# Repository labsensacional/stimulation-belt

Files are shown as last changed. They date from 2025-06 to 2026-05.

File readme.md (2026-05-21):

# Collar de Estimulación

En este proyecto mostramos como clonar el control de un collar de adiestramiento que tiene opciones de estimulos por vibracion, sonido e impulsos electricos.

## Captura de la señal

Para esto usamos el [Trainer 3](https://mundomascotas.com.ar/tienda/collar-de-adiestramiento-para-perros/trainer-3/) y el [flipper zero](https://en.wikipedia.org/wiki/Flipper_Zero) que amablemente nos prestaron Matt y Gia respectivamente.

[KinkyToyMaker](https://www.instagram.com/kinkytoymaker/?hl=en) grabó las señales que estan en la carpeta `subs`.

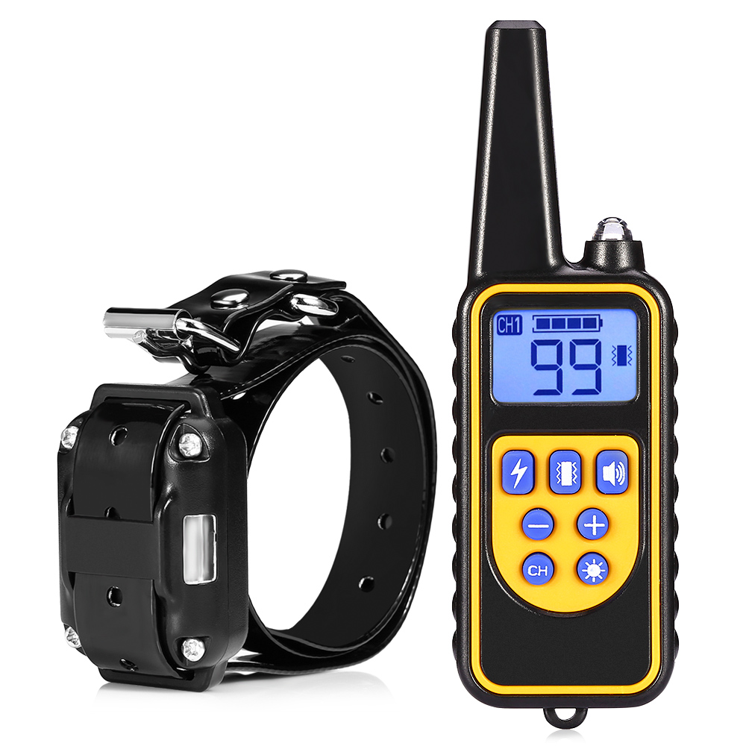
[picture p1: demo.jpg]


Compramos el collar sin control [acá](https://mundomascotas.com.ar/tienda/collares-extras/collar-extra-trainer3/)

## Hardware

Compramos distintos modulos RF de 433 MHZ para OOK y lo conectamos a una ESP32. Para debuggear y lograr que termine de funcionar todo nos guiamos de [este tutorial](https://youtu.be/LbCDpbWrdlQ?si=hX0qrkrM-xSeYEQN), el cual plantea conectar a la placa de sonido el receptor para grabar las señales que se reciben y comparar las del control que se quiere clonar con la de nuestro emisor.

- https://www.mercadolibre.com.ar/modulo-rf-transmisor-y-receptor-433-mhz-arduino/p/MLA32487770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
    - De este anduvo el receptor y no el transmisor

- https://articulo.mercadolibre.com.ar/MLA-780605460-emisor-receptor-superheterodino-433-armodltxrxwl102-_JM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
    - De este anduvo el transmisor y no el receptor

## Sketches ESP32

| Carpeta | Descripción |
|---|---|
| `src/Telegram_Bot` | Control por comandos de Telegram sobre WiFi |
| `src/BLE_Keyboard` | Dispara shocks al presionar teclas en un teclado BLE HID |
| `src/Dual_Mode` | **Fusión de ambos** — switchea entre modos con el botón BOOT |
| `src/Numpad_Serial` | **Sin BLE ni WiFi** — numpad 4×4 cableado directo + control por puerto serial |

### Numpad_Serial

Control standalone sin radio: un teclado matricial 4×4 conectado directamente a 8 pines del ESP32, más comandos por puerto serial desde una PC.

| Tecla | Función |
|---|---|
| `7` | Shock collar 1 |
| `8` | Shock collar 2 |
| `9` | Shock ambos |
| `4` / `5` | Nivel collar 1/2 +1 |
| `1` / `2` | Nivel collar 1/2 -1 |
| `0` | Ambos niveles +1 |
| `*` | Ambos niveles -1 |
| `6` / `3` | Test collar 1/2 (vibra + beep) |
| `#` | Reset niveles a 1 |

Incluye dos interfaces para la PC:
- `shocker_serial.py` — script Python (requiere `pip install pyserial`)
- `shocker_serial.html` — página web, abrila en Chrome o Edge (usa Web Serial API, no necesita instalar nada)

> **Windows:** puede ser necesario instalar el driver USB-serial del chip de la placa.
> El driver para CH340/CH341 (el más común en placas NodeMCU) o CP210x se puede bajar de:
> https://www.silabs.com/documents/public/software/CP210x_Universal_Windows_Driver.zip

### Dual_Mode — cómo switchear de modo

| Acción al encender | Resultado |
|---|---|
| No tocar nada | Arranca en el modo guardado (Telegram por defecto) |
| Mantener BOOT < 2 s y soltar | Cambia de modo (Telegram ↔ BLE Keyboard), guarda y reinicia |
| Mantener BOOT ≥ 2 s | Borra credenciales WiFi guardadas y reinicia |

El LED parpadea rápido mientras se sostiene el botón para confirmar que fue registrado.

### Compilar y subir

`Dual_Mode` requiere el esquema `huge_app` (WiFi + BLE juntos no entran en la partición por defecto):

```bash
~/.local/bin/arduino-cli compile \
  --fqbn "esp32:esp32:esp32:PartitionScheme=huge_app" \
  --upload --port /dev/ttyUSB0 \
  "src/Dual_Mode"
```

Para los sketches individuales:

```bash
~/.local/bin/arduino-cli compile \
  --fqbn esp32:esp32:esp32 \
  --upload --port /dev/ttyUSB0 \
  "src/Telegram_Bot"   # o src/BLE_Keyboard
```

## Proyectos Relacionados

- https://pishock.com/
- https://openshock.org/
    - https://wiki.openshock.org/hardware/shockers/caixianlin
- https://github.com/Nat-the-Kat/caixianlin_remote_shocker

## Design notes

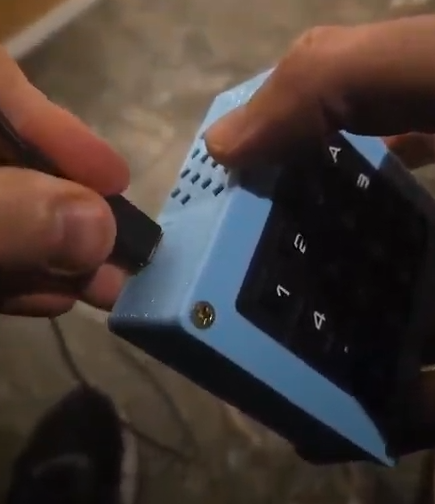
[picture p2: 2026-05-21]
src/Numpad_Serial/hardware/case-usbc.png

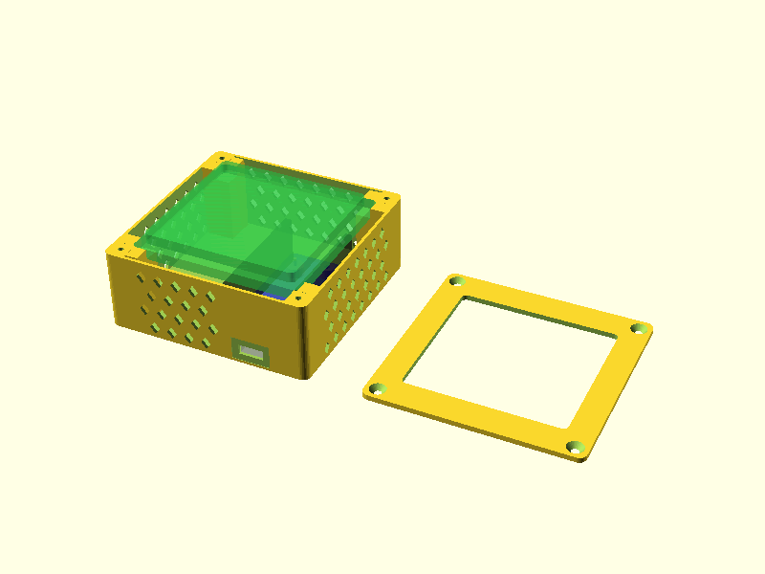
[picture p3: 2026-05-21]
src/Numpad_Serial/hardware/keypad_box_017.png

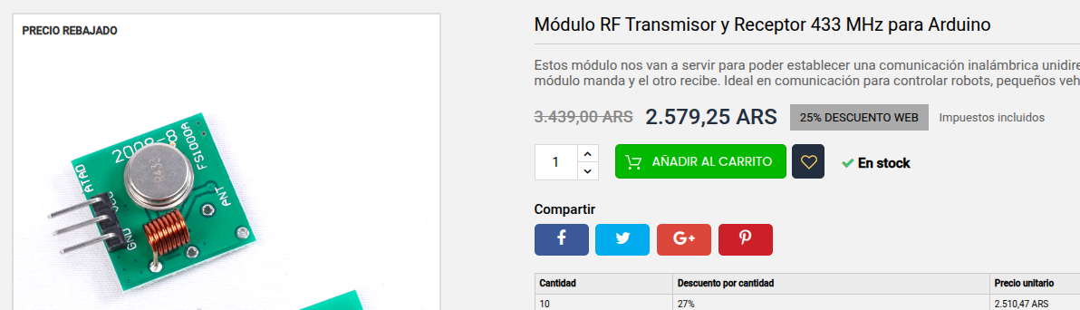
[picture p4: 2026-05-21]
src/Numpad_Serial/hardware/emisor433MHz.png

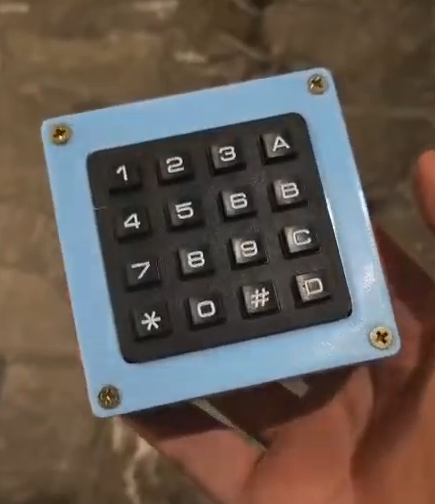
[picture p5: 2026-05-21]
src/Numpad_Serial/hardware/case.png

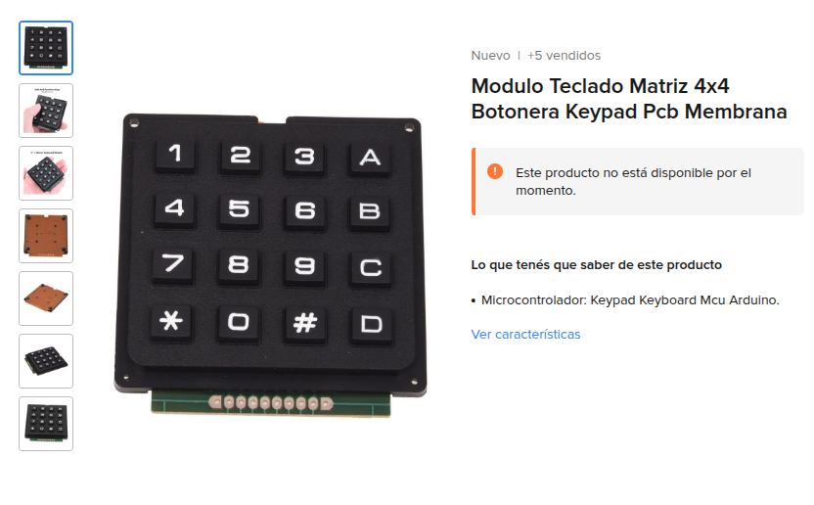
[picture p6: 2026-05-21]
src/Numpad_Serial/hardware/botonera.png

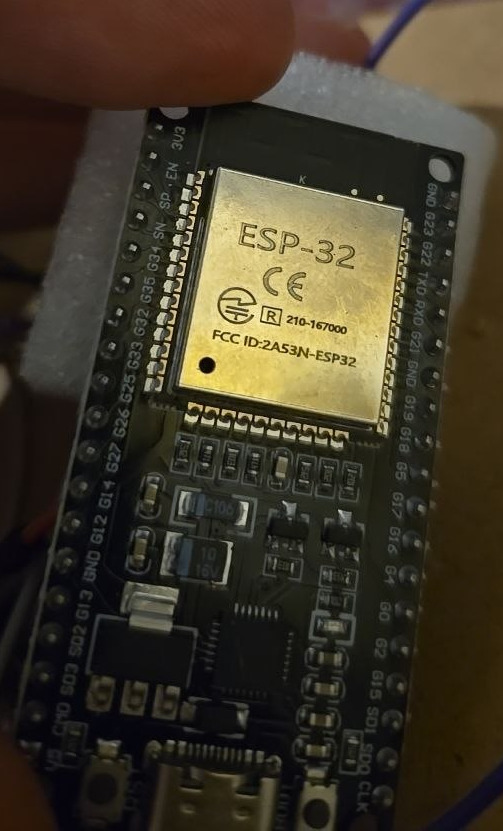
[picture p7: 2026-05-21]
src/Numpad_Serial/hardware/esp32-usbc.jpg

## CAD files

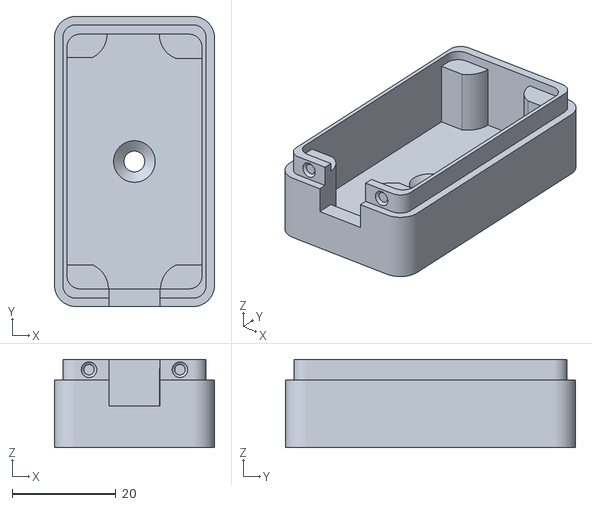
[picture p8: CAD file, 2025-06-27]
ESP Version/NodeMCU_bottom.stl
30.8 x 55.8 x 17.0

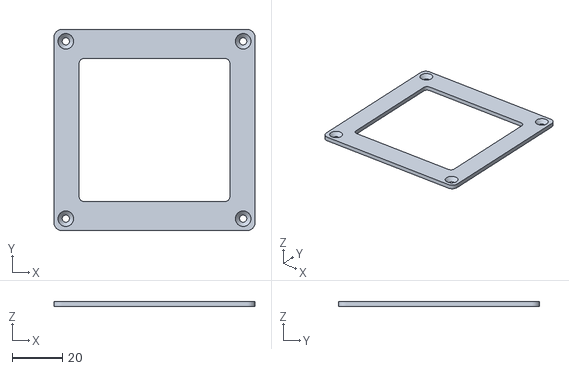
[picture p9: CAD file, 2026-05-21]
src/Numpad_Serial/hardware/keypad_box_017_lid.stl
80.0 x 80.0 x 2.00

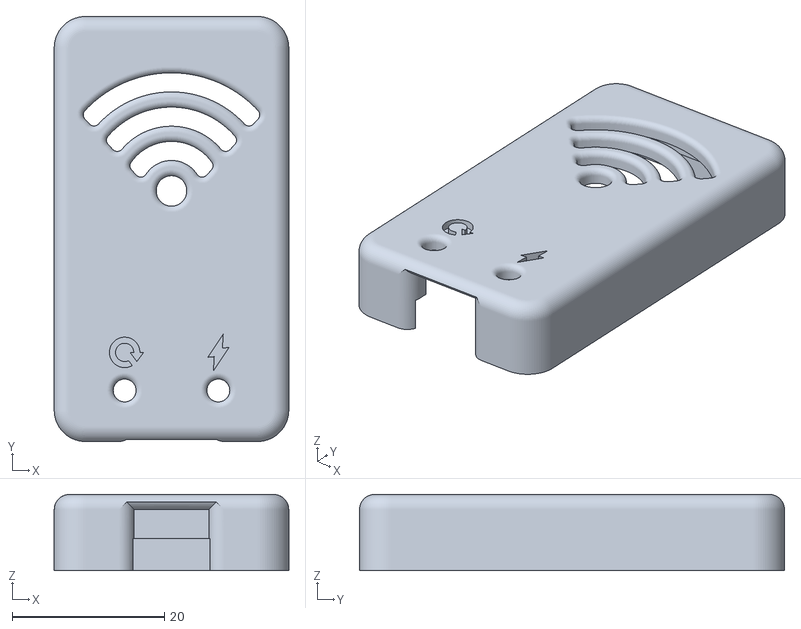
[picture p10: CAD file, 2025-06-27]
ESP Version/NodeMCU_top.stl
30.8 x 55.8 x 10.00

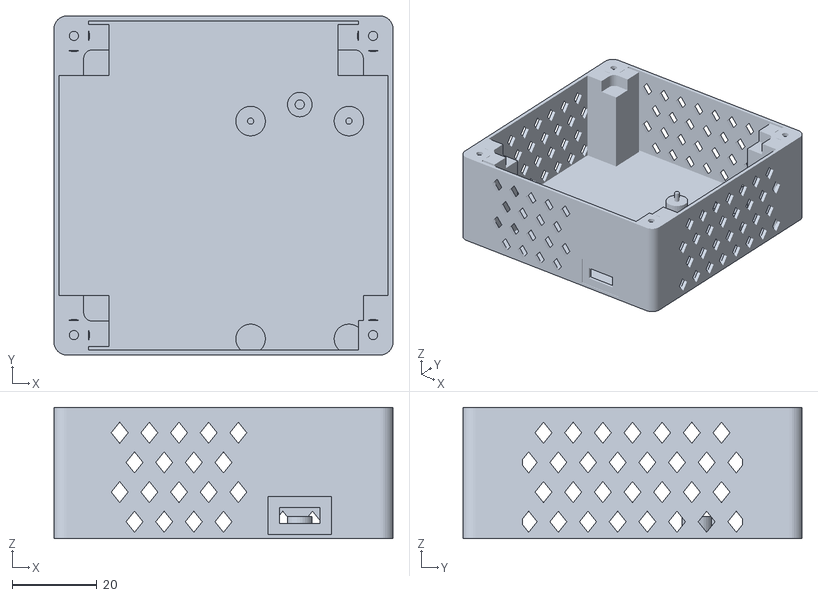
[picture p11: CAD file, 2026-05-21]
src/Numpad_Serial/hardware/keypad_box_017_body.stl
80.0 x 80.0 x 31.0

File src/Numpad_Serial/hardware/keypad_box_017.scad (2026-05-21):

include <NopSCADlib/lib.scad>

box_w = 80;
box_d = 80;
box_h = 31;
wall = 1.2;
box_corner_r = 3;

lid_t = 2;

lid_screw_d = 2.7;
lid_tap_d = 2.2;
lid_boss_od = 7;
lid_boss_r = lid_boss_od / 2;
lid_screw_head_d = 6.4;
lid_screw_head_h = 2.2;

esp32_board_l = 55;
esp32_board_w = 28;
esp32_board_t = 1.6;
esp32_corner_r = 2;

esp32_hole_margin_x = 2.4;
esp32_hole_margin_y = 2.3;
esp32_support_h = 4;
esp32_support_d = 7;
esp32_peg_d = 1.5;
esp32_peg_h = 3;
esp32_float_gap = 2;

front_hole_inset_y = max(0, esp32_hole_margin_y - 1);
rear_hole_inset_y = esp32_hole_margin_y;
rear_tube_extra_gap = 0.5;
screw_tube_h = 4;
screw_tube_hole_d = 2.2;
screw_tube_wall = 1.8;

preview_usb_w = 9;
preview_usb_d = 7;
preview_usb_h = 3.4;
preview_usb_shell_t = 0.6;
preview_usb_gap_below_board = 0;
preview_usb_overlap_with_board = 5.6;
usb_cutout_clearance_w = 0.6;
usb_cutout_clearance_above = 0.2;
usb_cutout_clearance_below = 0.2;
usb_relief_w = 15;
usb_relief_h = 9;
usb_relief_wall_t = 1;
preview_header_len = 46;
preview_header_w = 2.6;
preview_header_h = 18;
preview_header_inset = 1.7;

// Botonera dimensions
btn_base_w = 66;
btn_base_d = 64;
btn_base_t = 4;
btn_top_w  = 60;
btn_top_d  = 57;
btn_top_t  = 4;
btn_corner_r = 2;

show_esp_preview     = true;
show_botonera_preview = true;
part = "assembly"; // assembly, body, lid

esp32_board = pcb(
    "ESP32_38PIN_USBC_SUPPORT",
    "ESP32 38-pin USB-C board support reference",
    [esp32_board_l, esp32_board_w, esp32_board_t],
    corner_r = esp32_corner_r,
    hole_d = 2.2,
    colour = "#2140BE"
);

esp32_center = [58, 30];
esp32_board_bottom_z = wall + esp32_support_h + esp32_float_gap;
esp32_support_top_z = wall + esp32_support_h;
usb_cutout_w = preview_usb_w + usb_cutout_clearance_w;
usb_cutout_h = preview_usb_h + usb_cutout_clearance_above + usb_cutout_clearance_below;
usb_cutout_z = esp32_support_top_z - preview_usb_gap_below_board - preview_usb_h - usb_cutout_clearance_below + 2;
esp32_side_offset = pcb_width(esp32_board) / 2 - esp32_hole_margin_x;
esp32_front_x = -pcb_length(esp32_board) / 2 + front_hole_inset_y;
esp32_rear_x = pcb_length(esp32_board) / 2 - rear_hole_inset_y;
esp32_rear_tube_x = pcb_length(esp32_board) / 2 + screw_tube_hole_d / 2 + rear_tube_extra_gap;

corner_boss_x = [wall + lid_boss_r, box_w - wall - lid_boss_r];
corner_boss_y = [wall + lid_boss_r, box_d - wall - lid_boss_r];

vent_w           = 4;
vent_h           = 5;
vent_rows        = 4;
vent_row_spacing = 7;
vent_z_center    = 14.5;  // rows at z=4,11,18,25 within box_h=31

vent_even_cols = [-24.5, -17.5, -10.5, -3.5, 3.5, 10.5, 17.5, 24.5];
vent_odd_cols  = [-21, -14, -7, 0, 7, 14, 21];

vent_front_even_cols = [-24.5, -17.5, -10.5, -3.5, 3.5];
vent_front_odd_cols  = [-21, -14, -7, 0];

module rounded_rect_2d(w, d, r) {
    rr = min(r, w / 2, d / 2);
    hull()
        for (x = [rr, w - rr], y = [rr, d - rr])
            translate([x, y])
                circle(r = rr, $fn = 32);
}

module lid_screw_cut(lid_h) {
    countersink_h = min(lid_screw_head_h, lid_h + 0.1);
    translate([0, 0, -0.1])
        cylinder(d = lid_screw_d, h = lid_h + 0.2, $fn = 20);
    translate([0, 0, lid_h - countersink_h])
        cylinder(d1 = lid_screw_d, d2 = lid_screw_head_d, h = countersink_h + 0.1, $fn = 32);
}

module place_esp(z = esp32_board_bottom_z) {
    translate([esp32_center.x, esp32_center.y, z])
        rotate([0, 0, 90])
            children();
}

module esp32_support_post(with_peg = true) {
    support_wall = 1.2;
    difference() {
        cylinder(d = esp32_support_d, h = esp32_support_h, $fn = 28);
        translate([0, 0, -0.1])
            cylinder(d = esp32_support_d - 2 * support_wall, h = esp32_support_h - support_wall + 0.1, $fn = 20);
    }
    if (with_peg)
        translate([0, 0, esp32_support_h])
            cylinder(d = esp32_peg_d, h = esp32_peg_h, $fn = 20);
}

module screw_tube(h = screw_tube_h, hole_d = screw_tube_hole_d, wall_t = screw_tube_wall) {
    difference() {
        cylinder(d = hole_d + 2 * wall_t, h = h, $fn = 28);
        translate([0, 0, -0.1])
            cylinder(d = hole_d, h = h + 0.2, $fn = 20);
    }
}

module usb_cutout() {
    translate([esp32_center.x - usb_cutout_w / 2, -0.1, usb_cutout_z])
        cube([usb_cutout_w, wall + 0.2, usb_cutout_h]);
}

module usb_outer_relief() {
    translate([
        esp32_center.x - usb_relief_w / 2,
        -0.1,
        usb_cutout_z - (usb_relief_h - usb_cutout_h) / 2
    ])
        cube([usb_relief_w, wall - usb_relief_wall_t + 0.1, usb_relief_h]);
}

module esp32_supports() {
    place_esp(wall) {
        for (side_y = [-esp32_side_offset, esp32_side_offset]) {
            translate([esp32_front_x, side_y, 0])
                esp32_support_post(with_peg = false);
            translate([esp32_rear_x, side_y, 0])
                esp32_support_post(with_peg = true);
        }
        translate([esp32_rear_tube_x, 0, 0])
            screw_tube();
    }
}

module esp32_preview() {
    place_esp()
        color([0, 0, 1, 0.35])
            pcb(esp32_board);

    place_esp() {
        color([0.82, 0.82, 0.85, 0.55])
            translate([
                -esp32_board_l / 2 + preview_usb_overlap_with_board - preview_usb_d / 2,
                0,
                -preview_usb_gap_below_board - preview_usb_h / 2
            ])
                cube([preview_usb_d, preview_usb_w, preview_usb_h], center = true);

        color([0.15, 0.15, 0.15, 0.45])
            translate([
                -esp32_board_l / 2 + preview_usb_overlap_with_board - preview_usb_d / 2 + 0.4,
                0,
                -preview_usb_gap_below_board - preview_usb_h / 2
            ])
                cube([
                    preview_usb_d - 2 * preview_usb_shell_t,
                    preview_usb_w - 2 * preview_usb_shell_t,
                    preview_usb_h - 2 * preview_usb_shell_t
                ], center = true);

        color([0.05, 0.05, 0.05, 0.45])
            for (sy = [-1, 1])
                translate([
                    0,
                    sy * (esp32_board_w / 2 - preview_header_inset),
                    esp32_board_t + preview_header_h / 2
                ])
                    cube([preview_header_len, preview_header_w, preview_header_h], center = true);
    }
}

module rounded_btn_2d(w, d, r) {
    rr = min(r, w / 2, d / 2);
    hull()
        for (x = [rr, w - rr], y = [rr, d - rr])
            translate([x, y])
                circle(r = rr, $fn = 32);
}

btn_off_x = (box_w - btn_base_w) / 2;          // = 7  (centered)
btn_off_y = (box_d - btn_base_d) / 2;          // = 8  (centered)

// Centered botonera preview
module botonera_preview() {
    base_z = box_h - btn_base_t;
    color([0.2, 0.8, 0.3, 0.45]) {
        translate([btn_off_x, btn_off_y, base_z])
            linear_extrude(height = btn_base_t)
                rounded_btn_2d(btn_base_w, btn_base_d, btn_corner_r);
        translate([
            btn_off_x + (btn_base_w - btn_top_w) / 2,
            btn_off_y + (btn_base_d - btn_top_d) / 2,
            box_h
        ])
            linear_extrude(height = btn_top_t)
                rounded_btn_2d(btn_top_w, btn_top_d, btn_corner_r);
    }
}

col_sz = 6;

// Front-left corner: full L-bracket.
// Front-right corner: only extends toward right wall (no inner-x arm)
//   to avoid conflicting with ESP32 space at x=44..72.
module btn_front_columns() {
    // front-left: full square centered on corner (7, btn_off_y)
    translate([btn_off_x - col_sz, btn_off_y - col_sz, wall])
        cube([col_sz * 2, col_sz * 2, box_h - wall]);
    // front-right: only rightward from x=73 — "pegada a la pared"
    translate([btn_off_x + btn_base_w, btn_off_y - col_sz, wall])
        cube([col_sz, col_sz * 2, box_h - wall]);
}

// Back two corners: full L-bracket columns.
module btn_back_columns() {
    back_y = btn_off_y + btn_base_d;
    for (cx = [btn_off_x, btn_off_x + btn_base_w])
        translate([cx - col_sz, back_y - col_sz, wall])
            cube([col_sz * 2, col_sz * 2, box_h - wall]);
}

// Carves botonera footprint at z=18..22 from all columns.
module btn_botonera_cut() {
    translate([btn_off_x, btn_off_y, box_h - btn_base_t])
        linear_extrude(height = btn_base_t + 0.1)
            rounded_btn_2d(btn_base_w, btn_base_d, btn_corner_r);
}

// Clears screw-head access above each corner boss where columns overlap.
module column_screw_clearance() {
    for (bx = corner_boss_x)
        for (by = corner_boss_y)
            translate([bx, by, box_h - lid_screw_head_h - 0.1])
                cylinder(d = lid_screw_head_d + 1, h = lid_screw_head_h + 0.2, $fn = 28);
}

module hanging_corner_boss(cx, cy, sx, sy) {
    hang = 10;
    gusset_h = 10;
    start_z = box_h - hang;
    span = lid_boss_od + wall;
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

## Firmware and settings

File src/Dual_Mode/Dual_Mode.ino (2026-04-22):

/********************************************************************
 *  ESP32 RF-TRANSMITTER — DUAL MODE
 *  ---------------------------------------------------------------
 *  Hold BOOT (GPIO0) at power-on to select mode:
 *
 *    No press (default)  →  start in the previously saved mode
 *                           (first boot defaults to Telegram Bot)
 *    Release before 2 s  →  toggle mode (Telegram ↔ BLE Keyboard),
 *                           save choice and restart
 *    Hold for >= 2 s     →  clear saved WiFi credentials and restart
 *
 *  Mode 0 — Telegram Bot
 *    WiFi credentials stored via captive portal ("Shocker_Config" AP).
 *    Control shocks with Telegram commands.
 *
 *  Mode 1 — BLE Keyboard
 *    Scans for a BLE HID keyboard. Key presses fire shocks / adjust
 *    levels on a numpad layout.
 *    Keys: 7/8=shock  4/5=level+  1/2=level-  6/3=test  +/-=both  0=reset
 *
 *  RF wiring (433 MHz OOK module):
 *    DATA_PIN   → GPIO26
 *    ENABLE_PIN → GPIO27
 *
 *  Dependencies (Arduino Library Manager):
 *    • UniversalTelegramBot  (Brian Lough / witnessmenow)
 *    • ArduinoJson            (Benoit Blanchon)
 ********************************************************************/

// ── Mode constants ────────────────────────────────────────
#define MODE_TELEGRAM  0
#define MODE_BLE       1

// ── Includes ──────────────────────────────────────────────
#include <Arduino.h>
#include <EEPROM.h>

// Telegram mode
#include <WiFi.h>
#include <WiFiClientSecure.h>
#include <WebServer.h>
#include <UniversalTelegramBot.h>

// BLE mode
#include <BLEDevice.h>
#include <BLEUtils.h>
#include <BLEScan.h>
#include <BLEClient.h>
#include <BLESecurity.h>

// ── RF pin assignments ────────────────────────────────────
const uint8_t DATA_PIN   = 26;
const uint8_t ENABLE_PIN = 27;

#ifndef LED_BUILTIN
#define LED_BUILTIN 2
#endif

// ── Collar configuration ──────────────────────────────────
#define TRANSMITTER_ID  0xB497

// ── Telegram credentials ──────────────────────────────────
const char* BOT_TOKEN      = "7730578439:AAFxy1-uXIsE8c73HOsEb9axsZlmZ_kv684";
const char* HARDCODED_SSID = "si sos kinky y lo sabes, aplaudi";
const char* HARDCODED_PASS = "obligame";

// ── EEPROM layout ─────────────────────────────────────────
// [0]       credCount  (uint8)
// [1..640]  WiFi credentials  (5 × 128 bytes)
// [641]     active mode  (uint8: MODE_TELEGRAM or MODE_BLE)
#define MAX_CREDENTIALS  5
#define MODE_ADDR        641
#define EEPROM_SIZE      642

// ── RF action codes ───────────────────────────────────────
#define ACTION_SHOCK    1
#define ACTION_VIBRATE  2
#define ACTION_BEEP     3

// ═══════════════════════════════════════════════════════════
// RF — shared encoder + queue
// ═══════════════════════════════════════════════════════════

struct RFCmd {
  uint16_t txId;
  uint8_t  channel;
  uint8_t  action;
  uint8_t  intensity;
};

static QueueHandle_t rfQueue = nullptr;
#define RF_QUEUE_LEN 16

static void enqueueRF(uint8_t channel, uint8_t action, uint8_t intensity) {
  RFCmd cmd = { TRANSMITTER_ID, channel, action, intensity };
  if (xQueueSend(rfQueue, &cmd, 0) != pdTRUE)
    Serial.println("[RF] queue full — command dropped");
}

void sendStimulus(uint16_t txId, uint8_t channel, uint8_t action,
                  uint8_t intensity, uint8_t repeats = 10) {
  if (channel > 2)              channel   = 2;
  if (action < 1 || action > 3) action    = ACTION_SHOCK;
  if (intensity > 99)           intensity = 99;
  if (action == ACTION_BEEP)    intensity = 0;

  uint64_t payload = ((uint64_t)txId      << 24) |
                     ((uint64_t)channel   << 20) |
                     ((uint64_t)action    << 16) |
                     ((uint64_t)intensity <<  8);

  uint8_t checksum = 0;
  for (uint8_t i = 0; i < 5; i++)
    checksum += (uint8_t)((payload >> (i * 8)) & 0xFF);

  uint64_t packet = payload | (uint64_t)checksum;

  digitalWrite(ENABLE_PIN, HIGH);
  for (uint8_t r = 0; r < repeats; r++) {
    digitalWrite(DATA_PIN, HIGH); delayMicroseconds(1400);
    digitalWrite(DATA_PIN, LOW);  delayMicroseconds(750);
    for (int8_t b = 39; b >= 0; b--) {
      if ((packet >> b) & 1ULL) {
        digitalWrite(DATA_PIN, HIGH); delayMicroseconds(750);
        digitalWrite(DATA_PIN, LOW);  delayMicroseconds(250);
      } else {
        digitalWrite(DATA_PIN, HIGH); delayMicroseconds(250);
        digitalWrite(DATA_PIN, LOW);  delayMicroseconds(750);
      }
    }
    digitalWrite(DATA_PIN, HIGH); delayMicroseconds(250);
    digitalWrite(DATA_PIN, LOW);  delayMicroseconds(750);
    digitalWrite(DATA_PIN, HIGH); delayMicroseconds(250);
    digitalWrite(DATA_PIN, LOW);  delayMicroseconds(750);
  }
  digitalWrite(DATA_PIN, LOW);
  digitalWrite(ENABLE_PIN, LOW);
}

// ═══════════════════════════════════════════════════════════
// TELEGRAM BOT
// ═══════════════════════════════════════════════════════════

struct WiFiCred { char ssid[64]; char pass[64]; };

WiFiCred creds[MAX_CREDENTIALS];
uint8_t  credCount = 0;

WebServer            configServer(80);
WiFiClientSecure     tgClient;
UniversalTelegramBot* tgBot = nullptr;

unsigned long  tg_lastCheck   = 0;
const unsigned POLL_INTERVAL  = 500;

enum ChannelMode { CH_BOTH = 0, CH_1, CH_2, CH_INTERMITTENT };

static uint8_t      tg_intensity       = 5;
static uint32_t     tg_periodMs        = 2000;
static bool         tg_periodicRunning = false;
static unsigned long tg_lastShockMs    = 0;
static ChannelMode  tg_channelMode     = CH_BOTH;
static uint8_t      tg_intermittentCh  = 0;

static uint8_t clampIntensity(int v) {
  if (v < 1)  return 1;
  if (v > 99) return 99;
  return (uint8_t)v;
}

static uint32_t secondsToMs(int secs) {
  if (secs < 1)    secs = 1;
  if (secs > 3600) secs = 3600;
  return (uint32_t)secs * 1000UL;
}

const char* channelModeName() {
  switch (tg_channelMode) {
    case CH_BOTH:         return "ambos";
    case CH_1:            return "collar 1";
    case CH_2:            return "collar 2";
    case CH_INTERMITTENT: return "intermitente";
  }
  return "?";
}

void tg_doShock() {
  switch (tg_channelMode) {
    case CH_BOTH:
      enqueueRF(0, ACTION_SHOCK, tg_intensity);
      enqueueRF(1, ACTION_SHOCK, tg_intensity);
      break;
    case CH_1:
      enqueueRF(0, ACTION_SHOCK, tg_intensity);
      break;
    case CH_2:
      enqueueRF(1, ACTION_SHOCK, tg_intensity);
      break;
    case CH_INTERMITTENT:
      enqueueRF(tg_intermittentCh, ACTION_SHOCK, tg_intensity);
      tg_intermittentCh ^= 1;
      break;
  }
}

void tg_doTest() {
  auto enqueueTest = [](uint8_t ch) {
    enqueueRF(ch, ACTION_VIBRATE, 50);
    enqueueRF(ch, ACTION_BEEP, 0);
  };
  switch (tg_channelMode) {
    case CH_BOTH:        enqueueTest(0); enqueueTest(1); break;
    case CH_1:           enqueueTest(0);                 break;
    case CH_2:           enqueueTest(1);                 break;
    case CH_INTERMITTENT:
      enqueueTest(tg_intermittentCh);
      tg_intermittentCh ^= 1;
      break;
  }
}

void loadCreds() {
  EEPROM.begin(EEPROM_SIZE);
  credCount = EEPROM.read(0);
  if (credCount > MAX_CREDENTIALS) credCount = 0;
  for (uint8_t i = 0; i < credCount; i++)
    EEPROM.get(1 + i * sizeof(WiFiCred), creds[i]);
}

void saveCred(const char* s, const char* p) {
  for (uint8_t i = 0; i < credCount; i++) {
    if (strcmp(creds[i].ssid, s) == 0) {
      strncpy(creds[i].pass, p, sizeof(creds[0].pass) - 1);
      creds[i].pass[sizeof(creds[0].pass) - 1] = '\0';
      EEPROM.put(1 + i * sizeof(WiFiCred), creds[i]);
      EEPROM.commit();
      return;
    }
  }
  if (credCount >= MAX_CREDENTIALS) return;
  strncpy(creds[credCount].ssid, s, sizeof(creds[0].ssid) - 1);
  strncpy(creds[credCount].pass, p, sizeof(creds[0].pass) - 1);
  creds[credCount].ssid[sizeof(creds[0].ssid) - 1] = '\0';
  creds[credCount].pass[sizeof(creds[0].pass) - 1] = '\0';
  EEPROM.put(1 + credCount * sizeof(WiFiCred), creds[credCount]);
  credCount++;
  EEPROM.write(0, credCount);
  EEPROM.commit();
}

static bool tryConnect(const char* ssid, const char* pass) {
  Serial.printf("  trying '%s' … ", ssid);
  WiFi.disconnect(true);
  delay(200);
  WiFi.begin(ssid, pass);
  for (uint8_t j = 0; j < 60 && WiFi.status() != WL_CONNECTED; j++) {
    delay(500);
    digitalWrite(LED_BUILTIN, j % 2);
  }
  if (WiFi.status() == WL_CONNECTED) {
    digitalWrite(LED_BUILTIN, HIGH);
    Serial.println("OK");
    return true;
  }
  digitalWrite(LED_BUILTIN, LOW);
  Serial.printf("fail (status=%d)\n", WiFi.status());
  return false;
}

bool connectToKnown() {
  const char* hardPass = HARDCODED_PASS;
  for (uint8_t i = 0; i < credCount; i++) {
    if (strcmp(creds[i].ssid, HARDCODED_SSID) == 0) {
      hardPass = creds[i].pass;
      break;
    }
  }
  if (tryConnect(HARDCODED_SSID, hardPass)) return true;
  for (uint8_t i = 0; i < credCount; i++) {
    if (strcmp(creds[i].ssid, HARDCODED_SSID) == 0) continue;
    if (tryConnect(creds[i].ssid, creds[i].pass)) return true;
  }
  return false;
}

void startConfigPortal() {
  WiFi.mode(WIFI_AP);
  WiFi.softAP("Shocker_Config");
  IPAddress ip = WiFi.softAPIP();
  Serial.printf("Config AP – conectate a Shocker_Config y abrí http://%s/\n",
                ip.toString().c_str());

  configServer.on("/", HTTP_GET, []() {
    configServer.send(200, "text/html",
      "<form method='POST' action='/save'>"
      "SSID:<br><input name='s'><br>"
      "PASS:<br><input name='p' type='password'><br><br>"
      "<input type='submit' value='Guardar y reiniciar'></form>");
  });
  configServer.on("/save", HTTP_POST, []() {
    String ssid = configServer.arg("s");
    String pass = configServer.arg("p");
    if (ssid.length()) {
      saveCred(ssid.c_str(), pass.c_str());
      configServer.send(200, "text/html",
        "Guardado! Reiniciando…"
        "<script>setTimeout(()=>{location.href='/'},5000);</script>");
      delay(1000);
      ESP.restart();
    } else {
      configServer.send(400, "text/plain", "SSID missing");
    }
  });
  configServer.begin();
}

int parseIntensity(const String& text) {
  int pos = 0;
  if      (text.startsWith("/intensity")) pos = 10;
  else if (text.startsWith("intensity"))  pos = 9;
  else return -1;
  while (pos < (int)text.length() && text[pos] == ' ') pos++;
  if (pos >= (int)text.length() || !isDigit(text[pos])) return -1;
  int start = pos;
  while (pos < (int)text.length() && isDigit(text[pos])) pos++;
  int val = text.substring(start, pos).toInt();
  return (val >= 1 && val <= 99) ? val : -1;
}

int parsePeriod(const String& text) {
  int pos = 0;
  if      (text.startsWith("/period")) pos = 7;
  else if (text.startsWith("period"))  pos = 6;
  else return -1;
  while (pos < (int)text.length() && text[pos] == ' ') pos++;
  if (pos >= (int)text.length() || !isDigit(text[pos])) return -1;
  int start = pos;
  while (pos < (int)text.length() && isDigit(text[pos])) pos++;
  int val = text.substring(start, pos).toInt();
  return (val >= 1 && val <= 3600) ? val : -1;
}

void handleMessages(int numMsgs) {
  for (int i = 0; i < numMsgs; i++) {
    String chat_id = tgBot->messages[i].chat_id;
    String text    = tgBot->messages[i].text;
    text.toLowerCase();
    Serial.printf("[TG] chat=%s  text=%s\n", chat_id.c_str(), text.c_str());

    if (text == "/start" || text == "/help") {
      tgBot->sendMessage(chat_id,
        "⚡ Shocker Bot (ESP32) ⚡\n\n"
        "Comandos:\n"
        " /intensity N    – intensidad 1-99\n"
        " /period N       – periodo en segundos\n"
        " /shock          – shock único\n"
        " /periodic       – shocks periódicos (hasta /stop)\n"
        " /stop           – detener periódicos\n"
        " /ch1            – solo collar 1\n"
        " /ch2            – solo collar 2\n"
        " /both           – ambos collares (defecto)\n"
        " /intermittent   – alternar collar 1 y 2\n"
        " /test           – vibración + sonido (sin shock)\n"
        " /status         – ver configuración actual", "");
    } else if (text == "/status") {
      tgBot->sendMessage(chat_id,
        String("Estado actual:\n") +
        " Intensidad:  " + String(tg_intensity) + "\n"
        " Periodo:     " + String(tg_periodMs / 1000UL) + " s\n"
        " Canal:       " + channelModeName() + "\n"
        " Periodico:   " + (tg_periodicRunning ? "ON ⚡" : "OFF ⛔"), "");
    } else if (text.startsWith("/intensity") || text.startsWith("intensity")) {
      int val = parseIntensity(text);
      if (val > 0) {
        tg_intensity = (uint8_t)val;
        tgBot->sendMessage(chat_id, "Intensidad → " + String(tg_intensity), "");
      } else {
        tgBot->sendMessage(chat_id, "Uso: /intensity N  (1-99)", "");
      }
    } else if (text.startsWith("/period") || text.startsWith("period")) {
      int val = parsePeriod(text);
      if (val > 0) {
        tg_periodMs = secondsToMs(val);
        String msg = "Periodo → " + String(val) + " s";
        if (tg_periodicRunning) { msg += " (activo)"; tg_lastShockMs = millis(); }
        tgBot->sendMessage(chat_id, msg, "");
      } else {
        tgBot->sendMessage(chat_id, "Uso: /period N  (1-3600 segundos)", "");
      }
    } else if (text == "/shock") {
      tg_doShock();
      tgBot->sendMessage(chat_id,
        "⚡ Shock – intensidad " + String(tg_intensity) +
        "  canal: " + channelModeName(), "");
    } else if (text == "/periodic") {
      tg_periodicRunning = true;
      tg_lastShockMs     = millis() - tg_periodMs;
      tgBot->sendMessage(chat_id,
        String("⚡ Modo periodico ON ⚡\n") +
        " Intensidad: " + String(tg_intensity) + "\n"
        " Periodo:    " + String(tg_periodMs / 1000UL) + " s\n"
        " Canal:      " + channelModeName() + "\n\n"
        "Enviar /stop para detener.", "");
    } else if (text == "/stop") {
      tg_periodicRunning = false;
      tgBot->sendMessage(chat_id, "⛔ Modo periodico OFF", "");
    } else if (text == "/ch1") {
      tg_channelMode = CH_1;
      tgBot->sendMessage(chat_id, "Canal → collar 1 unicamente", "");
    } else if (text == "/ch2") {
      tg_channelMode = CH_2;
      tgBot->sendMessage(chat_id, "Canal → collar 2 unicamente", "");
    } else if (text == "/both") {
      tg_channelMode = CH_BOTH;
      tgBot->sendMessage(chat_id, "Canal → ambos collares", "");
    } else if (text == "/intermittent") {
      tg_channelMode    = CH_INTERMITTENT;
      tg_intermittentCh = 0;
      tgBot->sendMessage(chat_id, "Canal → intermitente (alternando collar 1 y 2)", "");
    } else if (text == "/test") {
      tg_doTest();
      tgBot->sendMessage(chat_id,
        "Test: vibracion + sonido  canal: " + String(channelModeName()), "");
    } else {
      tgBot->sendMessage(chat_id, "Comando no reconocido. Usa /start para ver la lista.", "");
    }
  }
}

void setupTelegram() {
  Serial.println("========================================");
  Serial.println("  MODO: Telegram Bot");
  Serial.printf ("  TX ID:      0x%04X\n", TRANSMITTER_ID);
  Serial.printf ("  DATA_PIN:   GPIO%d\n", DATA_PIN);
  Serial.printf ("  ENABLE_PIN: GPIO%d\n", ENABLE_PIN);
  Serial.println("========================================\n");

  loadCreds();
  Serial.printf("Redes guardadas: %d\n", credCount);
  for (uint8_t i = 0; i < credCount; i++)
    Serial.printf("  [%d] '%s'\n", i, creds[i].ssid);

  WiFi.mode(WIFI_STA);
  if (!connectToKnown()) {
    startConfigPortal();
  } else {
    tgClient.setInsecure();
    tgBot = new UniversalTelegramBot(BOT_TOKEN, tgClient);
    Serial.printf("WiFi OK  IP=%s\n", WiFi.localIP().toString().c_str());
    Serial.printf("Ready  intensity=%d  period=%lus  channel=%s\n",
                  tg_intensity, tg_periodMs / 1000UL, channelModeName());
  }
}

void loopTelegram() {
  configServer.handleClient();

  if (WiFi.getMode() == WIFI_AP) {
    digitalWrite(LED_BUILTIN, (millis() / 1000) % 2);
    return;
  }

  unsigned long now = millis();

  RFCmd cmd;
  while (xQueueReceive(rfQueue, &cmd, 0) == pdTRUE)
    sendStimulus(cmd.txId, cmd.channel, cmd.action, cmd.intensity);

  if (tg_periodicRunning && (now - tg_lastShockMs >= tg_periodMs)) {
    tg_lastShockMs = now;
    tg_doShock();
  }

  if (tgBot && now - tg_lastCheck >= POLL_INTERVAL) {
    tg_lastCheck = now;
    int n = tgBot->getUpdates(tgBot->last_message_received + 1);
    while (n) {
      handleMessages(n);
      n = tgBot->getUpdates(tgBot->last_message_received + 1);
    }
  }
}

// ═══════════════════════════════════════════════════════════
// BLE KEYBOARD
// ═══════════════════════════════════════════════════════════

static BLEUUID hidServiceUUID("1812");
static BLEUUID reportCharUUID("2a4d");

static BLEAdvertisedDevice* targetDevice     = nullptr;
static BLEClient*           bleClient        = nullptr;
static bool                 doConnect        = false;
static bool                 ble_connected    = false;
static unsigned long        disconnectTimeMs = 0;
static unsigned long        lastHeartbeatMs  = 0;
static uint8_t              levelCh1         = 1;
static uint8_t              levelCh2         = 1;

#define RECONNECT_DELAY_MS  3000
#define HEARTBEAT_MS        5000

static uint8_t clampLevel(int v) {
  if (v < 1)  return 1;
  if (v > 99) return 99;
  return (uint8_t)v;
}

class SecurityCB : public BLESecurityCallbacks {
  uint32_t onPassKeyRequest() override { return 0; }
  void onPassKeyNotify(uint32_t passkey) override {
    Serial.printf("[SEC] Passkey: %06lu\n", passkey);
  }
  bool onSecurityRequest() override { return true; }
  bool onConfirmPIN(uint32_t pin) override { return true; }
  void onAuthenticationComplete(esp_ble_auth_cmpl_t auth) override {
    Serial.printf("[SEC] Auth %s\n", auth.success ? "OK" : "FAILED");
  }
};

void onHIDReport(BLERemoteCharacteristic* chr, uint8_t* data,
                 size_t len, bool isNotify) {
  if (len < 3) return;
  uint8_t mod = data[0];
  uint8_t key = data[2];
  if (key == 0) return;

  Serial.printf("[HID] key=0x%02X  mod=0x%02X\n", key, mod);

  switch (key) {
    // Shock
    case 0x24: case 0x5F:
      enqueueRF(0, ACTION_SHOCK, levelCh1); break;
    case 0x25: case 0x60:
      enqueueRF(1, ACTION_SHOCK, levelCh2); break;
    // Level +1
    case 0x21: case 0x5C:
      levelCh1 = clampLevel(levelCh1 + 1);
      Serial.printf("[KEY] Ch1=%d\n", levelCh1); break;
    case 0x22: case 0x5D:
      levelCh2 = clampLevel(levelCh2 + 1);
      Serial.printf("[KEY] Ch2=%d\n", levelCh2); break;
    // Level -1
    case 0x1E: case 0x59:
      levelCh1 = clampLevel(levelCh1 - 1);
      Serial.printf("[KEY] Ch1=%d\n", levelCh1); break;
    case 0x1F: case 0x5A:
      levelCh2 = clampLevel(levelCh2 - 1);
      Serial.printf("[KEY] Ch2=%d\n", levelCh2); break;
    // Test (vibrate + beep)
    case 0x23: case 0x5E:
      enqueueRF(0, ACTION_VIBRATE, levelCh1);
      enqueueRF(0, ACTION_BEEP, 0); break;
    case 0x20: case 0x5B:
      enqueueRF(1, ACTION_VIBRATE, levelCh2);
      enqueueRF(1, ACTION_BEEP, 0); break;
    // Both +1
    case 0x57:
      levelCh1 = clampLevel(levelCh1 + 1);
      levelCh2 = clampLevel(levelCh2 + 1);
      Serial.printf("[KEY] Ch1=%d Ch2=%d\n", levelCh1, levelCh2); break;
    case 0x2E:
      if (mod & 0x22) {
        levelCh1 = clampLevel(levelCh1 + 1);
        levelCh2 = clampLevel(levelCh2 + 1);
        Serial.printf("[KEY] Ch1=%d Ch2=%d\n", levelCh1, levelCh2);
      }
      break;
    // Both -1
    case 0x56: case 0x2D:
      levelCh1 = clampLevel(levelCh1 - 1);
      levelCh2 = clampLevel(levelCh2 - 1);
      Serial.printf("[KEY] Ch1=%d Ch2=%d\n", levelCh1, levelCh2); break;
    // Reset
    case 0x27: case 0x62:
      levelCh1 = levelCh2 = 1;
      Serial.println("[KEY] reset Ch1=Ch2=1"); break;
    default: break;
  }
}

class ScanCB : public BLEAdvertisedDeviceCallbacks {
  void onResult(BLEAdvertisedDevice dev) override {
    if (dev.haveServiceUUID() && dev.isAdvertisingService(hidServiceUUID)) {
      Serial.printf("[SCAN] HID device: %s\n",
                    dev.getAddress().toString().c_str());
      targetDevice = new BLEAdvertisedDevice(dev);
      doConnect    = true;
      dev.getScan()->stop();
    }
  }
};

class ClientCB : public BLEClientCallbacks {
  void onConnect(BLEClient* c) override {
    Serial.println("[BLE] Connected");
  }
  void onDisconnect(BLEClient* c) override {
    Serial.println("[BLE] Disconnected — will retry");
    ble_connected    = false;
    disconnectTimeMs = millis();
  }
};

bool connectToDevice() {
  Serial.printf("[BLE] Connecting to %s …\n",
                targetDevice->getAddress().toString().c_str());
  if (!bleClient) {
    bleClient = BLEDevice::createClient();
    bleClient->setClientCallbacks(new ClientCB());
  }
  if (!bleClient->connect(targetDevice)) return false;

  esp_bd_addr_t addr;
  memcpy(addr, targetDevice->getAddress().getNative(), 6);
  esp_ble_set_encryption(addr, ESP_BLE_SEC_ENCRYPT_MITM);
  delay(2000);

  BLERemoteService* svc = bleClient->getService(hidServiceUUID);
  if (!svc) { bleClient->disconnect(); return false; }

  auto* chars = svc->getCharacteristics();
  int subscribed = 0;
  for (auto& kv : *chars) {
    BLERemoteCharacteristic* c = kv.second;
    if (c->getUUID().equals(reportCharUUID) && c->canNotify()) {
      c->registerForNotify(onHIDReport);
      subscribed++;
    }
  }
  if (subscribed == 0) { bleClient->disconnect(); return false; }
  Serial.printf("[BLE] Ready — subscribed to %d characteristic(s)\n", subscribed);
  return true;
}
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
void loop() {
  if (activeMode == MODE_BLE) {
    loopBLE();
  } else {
    loopTelegram();
  }
}

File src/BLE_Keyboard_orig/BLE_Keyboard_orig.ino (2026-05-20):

/********************************************************************
 *  ESP32  RF-TRANSMITTER + BLE KEYBOARD TRIGGER
 *  ---------------------------------------------------------------
 *  Scans for a BLE HID keyboard and connects to the first one
 *  found.  Any key press fires a level-1 shock on the configured
 *  channel using the CaiXianlin OOK protocol (fully encoded in
 *  firmware — no hardcoded captured waveforms).
 *
 *  IMPORTANT: Requires an ESP32.  The ESP8266 has no Bluetooth
 *  hardware and cannot run this sketch.
 *
 *  Before flashing:
 *    1. Set TRANSMITTER_ID to the 16-bit ID your collar is paired
 *       to.  You can find it by decoding one of the .sub files
 *       with a Flipper Zero or by putting the collar in pairing
 *       mode and using any value you like.
 *    2. Channels 0 and 1 are used (mapped to keys 7/4/1 and 8/5/2).
 *
 *  RF wiring (433 MHz OOK module with ENABLE pin):
 *    DATA_PIN   → DATA pin of transmitter
 *    ENABLE_PIN → ENABLE / VCC-switch pin of transmitter
 *
 *  Board: ESP32 Dev Module (or any ESP32 variant)
 *  Serial monitor baud rate: 115200
 ********************************************************************/

#include <Arduino.h>
#include <BLEDevice.h>
#include <BLEUtils.h>
#include <BLEScan.h>
#include <BLEClient.h>
#include <BLESecurity.h>

// ---------------- RF pin assignments ----------------
const uint8_t DATA_PIN   = 26;  // GPIO26 — same side as VIN/3V3
const uint8_t ENABLE_PIN = 27;  // GPIO27 — same side as VIN/3V3

// ---------------- Collar configuration ----------------
#define TRANSMITTER_ID  0xB497

// -------------------------------------------------------
// CaiXianlin OOK Protocol Encoder
// -------------------------------------------------------
// Action codes
#define ACTION_SHOCK    1
#define ACTION_VIBRATE  2
#define ACTION_BEEP     3

// ---------------- Per-channel intensity levels (1–99) ----------------
static uint8_t levelCh1 = 1;
static uint8_t levelCh2 = 1;

static uint8_t clampLevel(int v) {
  if (v < 1)  return 1;
  if (v > 99) return 99;
  return (uint8_t)v;
}

// ---------------- RF command queue ----------------
// sendStimulus() blocks for ~440 ms (busy-wait bit-banging).
// Calling it directly from the BLE notification callback starves the
// BLE stack task and causes missed/delayed notifications.
// Instead, the callback posts a command here and loop() executes it.
struct RFCmd {
  uint16_t txId;
  uint8_t  channel;
  uint8_t  action;
  uint8_t  intensity;
};

static QueueHandle_t rfQueue = nullptr;
#define RF_QUEUE_LEN 8

void sendStimulus(uint16_t txId, uint8_t channel, uint8_t action,
                  uint8_t intensity, uint8_t repeats = 10) {

  if (channel > 2) channel = 2;
  if (action < 1 || action > 3) action = ACTION_SHOCK;
  if (intensity > 99) intensity = 99;
  if (action == ACTION_BEEP) intensity = 0;

  const char* actionName = (action == ACTION_SHOCK)   ? "SHOCK"
                         : (action == ACTION_VIBRATE) ? "VIBRATE"
                                                      : "BEEP";

  uint64_t payload = ((uint64_t)txId      << 24) |
                     ((uint64_t)channel   << 20) |
                     ((uint64_t)action    << 16) |
                     ((uint64_t)intensity <<  8);

  uint8_t checksum = 0;
  for (uint8_t i = 0; i < 5; i++) {
    checksum += (uint8_t)((payload >> (i * 8)) & 0xFF);
  }

  uint64_t packet = payload | (uint64_t)checksum;

  Serial.printf("[RF] >>> TX  txId=0x%04X  ch=%d  action=%s  intensity=%d"
                "  checksum=0x%02X  repeats=%d\n",
                txId, channel, actionName, intensity, checksum, repeats);
  Serial.printf("[RF]     packet bits (hex): %02X %02X %02X %02X %02X\n",
                (uint8_t)(packet >> 32), (uint8_t)(packet >> 24),
                (uint8_t)(packet >> 16), (uint8_t)(packet >>  8),
                (uint8_t)(packet));

  digitalWrite(ENABLE_PIN, HIGH);

  for (uint8_t r = 0; r < repeats; r++) {
    digitalWrite(DATA_PIN, HIGH); delayMicroseconds(1400);
    digitalWrite(DATA_PIN, LOW);  delayMicroseconds(750);

    for (int8_t b = 39; b >= 0; b--) {
      if ((packet >> b) & 1ULL) {
        digitalWrite(DATA_PIN, HIGH); delayMicroseconds(750);
        digitalWrite(DATA_PIN, LOW);  delayMicroseconds(250);
      } else {
        digitalWrite(DATA_PIN, HIGH); delayMicroseconds(250);
        digitalWrite(DATA_PIN, LOW);  delayMicroseconds(750);
      }
    }
    // End marker: two 0-bits
    digitalWrite(DATA_PIN, HIGH); delayMicroseconds(250);
    digitalWrite(DATA_PIN, LOW);  delayMicroseconds(750);
    digitalWrite(DATA_PIN, HIGH); delayMicroseconds(250);
    digitalWrite(DATA_PIN, LOW);  delayMicroseconds(750);
  }

  digitalWrite(DATA_PIN, LOW);
  digitalWrite(ENABLE_PIN, LOW);
  Serial.printf("[RF] <<< done (%d repeats sent)\n", repeats);
}

// -------------------------------------------------------
// BLE HID client
// -------------------------------------------------------
static BLEUUID hidServiceUUID("1812");
static BLEUUID reportCharUUID("2a4d");

static BLEAdvertisedDevice* targetDevice  = nullptr;
static BLEClient*           bleClient     = nullptr;
static bool                 doConnect     = false;
static bool                 connected     = false;
static unsigned long        disconnectTimeMs = 0;
static unsigned long        lastHeartbeatMs  = 0;

#define RECONNECT_DELAY_MS  3000
#define HEARTBEAT_MS        5000   // print status every 5 s

// ── BLE security (Just Works / bonding) ─────────────────
class SecurityCB : public BLESecurityCallbacks {
  uint32_t onPassKeyRequest() override {
    Serial.println("[SEC] Passkey requested from us — sending 0");
    return 0;
  }
  void onPassKeyNotify(uint32_t passkey) override {
    Serial.printf("[SEC] Passkey notify: %06lu\n", passkey);
  }
  bool onSecurityRequest() override {
    Serial.println("[SEC] Security request received — accepting");
    return true;
  }
  bool onConfirmPIN(uint32_t pin) override {
    Serial.printf("[SEC] Confirm PIN %06lu — accepting\n", pin);
    return true;
  }
  void onAuthenticationComplete(esp_ble_auth_cmpl_t auth) override {
    if (auth.success) {
      Serial.println("[SEC] Authentication + bonding OK");
    } else {
      Serial.printf("[SEC] Authentication FAILED  reason=0x%02X\n",
                    auth.fail_reason);
    }
  }
};

// ── Helper: enqueue an RF command (safe to call from BLE task) ───────
static void enqueueRF(uint8_t channel, uint8_t action, uint8_t intensity) {
  RFCmd cmd = { TRANSMITTER_ID, channel, action, intensity };
  if (xQueueSend(rfQueue, &cmd, 0) != pdTRUE) {
    Serial.println("[RF] queue full — command dropped");
  }
}
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
